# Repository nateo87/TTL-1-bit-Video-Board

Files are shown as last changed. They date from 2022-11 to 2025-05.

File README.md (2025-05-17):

# TTL-1-bit-Video-Board
<s><i><b>UPDATE 2/2/2025:</b></i>

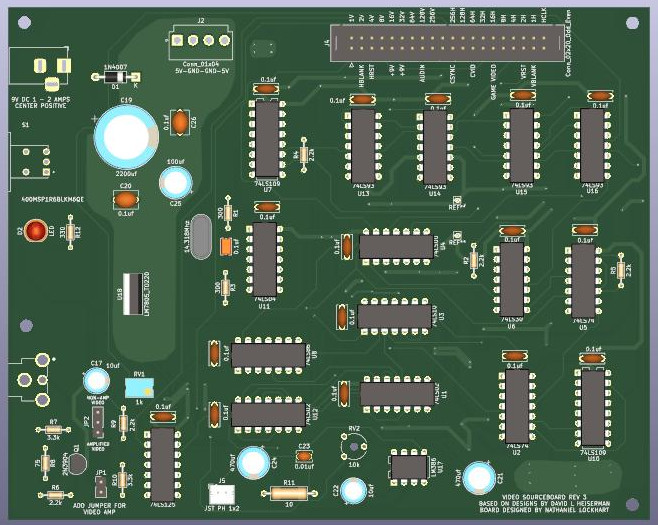
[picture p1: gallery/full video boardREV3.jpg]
new board render from KiCad


Did another revision of the board. The one I had up here previously was one of my first projects in KiCad, moving away from EasyEDA. The main changes with this revision have to do with size: the board is MUCH smaller, and the footprints for a lot of the passive components have been assigned more appropriately sized designs. I also swapped out the no-longer-produced 74LS76 IC with the much easier to source 74LS109. Still functions the exact same, only difference is pinout and 'K' is now active LOW instead of HIGH. ANYWAYS, on to what I wrote previously: </s>

<b>UPDATE: 5/12/2025 </b>
Just built one of the newest revision, and whaddya know, a 74LS109 <i>will not</i> work in place of a 74LS76! I built a board over the weekend, and thought maybe I was dealing with bad PCB design that was creating ringing or cross-talk between signals. But nope - it has to use a <i>negative edge</i> triggered JK flip-flop instead of a positive edge trigger. I bodged in a 74LS112 and all was well. I'm currently working on a revision to use the 74LS112 instead. 

<b>UPDATE: 5/16/2025 </b>
I updated the board to use a (still produced) 74LS112 in place of the non-working 74LS109. Circuit should be fully functional now. Now to design a 3D printed enclosure!

<i>end of update</i>

Here is a TTL-based, 1-bit video board as designed by David L. Heiserman in the book How to Design and Build Your Own Custom TV Games. Corrections have been made from the schematics in the book, mostly just pin number confusions (the later schematics have much more troublesome errors).

The original design has the outputs all going to a card edge connector, but I thought a 40-pin IDC connector would be a little more friendly, and an adapter can easily be purchased so that an IDC cable can plug into a breadboard for experimentation. Another thing that has been changed from the original design is the analog video output. Though it is still B&W composite, the values of the resistors dividing the voltage have changed, in order to massage the signal to be more easily accepted among a wider range of RF modulators and monitors. Some TVs/monitors tend to be a little pickier about the signal being put into them. In my experimentation, most CRT TVs with a direct composite input tend to be more forgiving with the signal. Jumpers can be placed to activate an amplification of the video signal for more selective monitors.

The text of Heiserman's book can easily be found online on [archive.org](https://archive.org/details/howtodesignbuild0000heis_n7e2), and I highly encourage trying some of the builds in the book, if only so that I'm not the only one crazy enough to be working through them! I haven't ordered boards yet from this most recent revision (V3), but once I do, I'll have pics of the assembled product running some experiments. 

Here's a video of an earlier revision of the board running a simple moveable square circuit:
(https://www.youtube.com/watch?v=p2fEVsLSzvE&t=35s)

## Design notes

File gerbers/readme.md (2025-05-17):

Here are the updated gerber files for the smaller video board with the correct, negative-edge JK flip-flop IC used.

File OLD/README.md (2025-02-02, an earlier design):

Here's everything from the earlier revision for posterity. <b>THIS IS NOT CURRENT</b>

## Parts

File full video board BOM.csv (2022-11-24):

Id | Designator | Quantity | Designation
1 | C17, C25 | 2 | 100uf, electrolytic
2 | C19 | 1 | 2200uf, electrolytic
3 | C1,C2,C3,C4,C5,C13,C11,C16,C18,C8,C12,C6,C9,C10,C7,C15,C14,C26,C20 | 19 | 0.1uf
4 | C21,C24 | 2 | 470uf, electrolytic
5 | C22 | 1 | 10uf, electrolytic
6 | C23 | 1 | 0.01uf
7 | D1 | 1 | 1N4007
8 | D2 | 1 | LED
9 | J1 | 1 | RCA Jack
10 | J2 | 1 | 2x20 IDC socket, 2.54mm pitch
11 | J3 | 1 | Barrel_Jack_MountingPin, 5.5x2.1
12 | J4 | 1 | JST VH 1x4
13 | J5 | 1 | JST PH 1x2
14 | JP1 | 1 | 2.54 header pins
15 | JP2 | 1 | 2.54 header pins
16 | Q1 | 1 | 2N3904 or 2N2222
17 | R1,R2 | 2 | 300ohm
18 | R10,R7 | 2 | 3.3k
19 | R11 | 1 | 10ohm
20 | R12 | 1 | 330ohm
21 | R4,R3,R6,R9,R5 | 5 | 2.2k
22 | R8 | 1 | 75ohm
23 | RV1 | 1 | 10k pot
24 | RV2 | 1 | Bourns trim pot, 1k
25 | S1 | 1 | 300SP1J1BLKM6QE, switch
26 | U1 | 1 | 74LS04
27 | U10,U2 | 2 | 74LS76
28 | U12,U3,U11,U4 | 4 | 74LS93
29 | U13,U15 | 2 | 74LS02
30 | U14 | 1 | 74LS86
31 | U16 | 1 | 74LS125
32 | U18 | 1 | LM386
33 | U19 | 1 | LM78S05
34 | U6 | 1 | 74LS00
35 | U7 | 1 | 74LS30
36 | U8 | 1 | 74LS10
37 | U9,U5 | 2 | 74LS74
38 | Y1 | 1 | 14.318Mhz

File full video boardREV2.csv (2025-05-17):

Source: | C:\Users\nateo\OneDrive\Documents\power supply\full video board\full video boardREV2.kicad_sch
Date: | 5/16/2025 11:02:02 PM
Tool: | Eeschema (6.0.5)
Generator: | C:\Program Files\KiCad\6.0\bin\scripting\plugins/bom_csv_grouped_by_value_with_fp.py
Component Count: | 70
Ref | Qnty | Value | Cmp name | Footprint | Description | Vendor
C1, C2, C3, C4, C5, C6, C7, C8, C9, C10, C11, C12, C14, C15, C16, C18, | 16 | 0.1uf | C | Capacitor_THT:C_Disc_D6.0mm_W2.5mm_P5.00mm | Unpolarized capacitor
C13, | 1 | 0.1uf | C | Capacitor_THT:C_Rect_L4.0mm_W2.5mm_P2.50mm | Unpolarized capacitor
C17, C22, | 2 | 10uf | C_Polarized | Capacitor_THT:CP_Radial_D6.3mm_P2.50mm | Polarized capacitor
C19, | 1 | 2200uf | C_Polarized | Capacitor_THT:CP_Radial_D16.0mm_P7.50mm | Polarized capacitor
C20, C26, | 2 | 0.1uf | C | Capacitor_THT:C_Disc_D6.0mm_W4.4mm_P5.00mm | Unpolarized capacitor
C21, C24, | 2 | 470uf | C_Polarized | Capacitor_THT:CP_Radial_D8.0mm_P3.80mm | Polarized capacitor
C23, | 1 | 0.01uf | C | Capacitor_THT:C_Disc_D3.8mm_W2.6mm_P2.50mm | Unpolarized capacitor
C25, | 1 | 100uf | C_Polarized | Capacitor_THT:CP_Radial_D8.0mm_P3.50mm | Polarized capacitor
D1, | 1 | 1N4007 | 1N4007 | Diode_THT:D_DO-41_SOD81_P10.16mm_Horizontal | 1000V 1A General Purpose Rectifier Diode, DO-41
D2, | 1 | LED | LED | LED_THT:LED_D5.0mm | Light emitting diode
J1, | 1 | RCJ-014 | RCJ-014 | footprints:CUI_RCJ-014
J2, | 1 | Conn_01x04 | Conn_01x04 | Connector_JST:JST_VH_B4P-VH-B_1x04_P3.96mm_Vertical | Generic connector, single row, 01x04, script generated (kicad-library-utils/schlib/autogen/connector/)
J3, | 1 | Barrel_Jack_MountingPin | Barrel_Jack | Connector_BarrelJack:BarrelJack_Horizontal | DC Barrel Jack
J4, | 1 | Conn_02x20_Odd_Even | Conn_02x20_Odd_Even | Connector_IDC:IDC-Header_2x20_P2.54mm_Vertical | Generic connector, double row, 02x20, odd/even pin numbering scheme (row 1 odd numbers, row 2 even numbers), script generated (kicad-library-utils/schlib/autogen/connector/)
J5, | 1 | JST PH 1x2 | Conn_01x02 | Connector_JST:JST_PH_B2B-PH-K_1x02_P2.00mm_Vertical | Generic connector, single row, 01x02, script generated (kicad-library-utils/schlib/autogen/connector/)
JP1, | 1 | Jumper_2_Open | Jumper_2_Open | Connector_PinHeader_2.54mm:PinHeader_1x02_P2.54mm_Vertical | Jumper, 2-pole, open
JP2, | 1 | Jumper_3_Open | Jumper_3_Open | Connector_PinHeader_2.54mm:PinHeader_1x03_P2.54mm_Vertical | Jumper, 3-pole, both open
Q1, | 1 | 2N3904 | 2N3904 | Package_TO_SOT_THT:TO-92_Inline | 0.2A Ic, 40V Vce, Small Signal NPN Transistor, TO-92
R1, R3, | 2 | 300 | R | Resistor_THT:R_Axial_DIN0204_L3.6mm_D1.6mm_P7.62mm_Horizontal | Resistor
R2, R4, R5, R6, R9, | 5 | 2.2k | R | Resistor_THT:R_Axial_DIN0204_L3.6mm_D1.6mm_P7.62mm_Horizontal | Resistor
R7, R10, | 2 | 3.3k | R | Resistor_THT:R_Axial_DIN0204_L3.6mm_D1.6mm_P7.62mm_Horizontal | Resistor
R8, | 1 | 75 | R | Resistor_THT:R_Axial_DIN0204_L3.6mm_D1.6mm_P7.62mm_Horizontal | Resistor
R11, | 1 | 10 | R | Resistor_THT:R_Axial_DIN0309_L9.0mm_D3.2mm_P12.70mm_Horizontal | Resistor
R12, | 1 | 330 | R | Resistor_THT:R_Axial_DIN0204_L3.6mm_D1.6mm_P7.62mm_Horizontal | Resistor
RV1, | 1 | 1k | R_Potentiometer | Potentiometer_THT:Potentiometer_Bourns_3266Y_Vertical | Potentiometer
RV2, | 1 | 10k | R_Potentiometer_US | Potentiometer_THT:Potentiometer_Piher_PT-6-V_Vertical_Hole | Potentiometer, US symbol
S1, | 1 | 400MSP1R6BLKM6QE | 300SP1J1BLKM6QE | 300SP1J1BLKM6QE:SW_400MSP1R6BLKM6QE
U1, U12, | 2 | 74LS02 | 74LS02 | Package_DIP:DIP-14_W7.62mm | quad 2-input NOR gate
U2, U5, | 2 | 74LS74 | 74LS74 | Package_DIP:DIP-14_W7.62mm | Dual D Flip-flop, Set & Reset
U3, | 1 | 74LS10 | 74LS10 | Package_DIP:DIP-14_W7.62mm | Triple 3-input NAND
U4, | 1 | 74LS00 | 74LS00 | Package_DIP:DIP-14_W7.62mm | quad 2-input NAND gate
U6, | 1 | 74LS30 | 74LS30 | Package_DIP:DIP-14_W7.62mm | 8-input NAND
U7, U10, | 2 | 74LS112 | 74LS112 | Package_DIP:DIP-16_W7.62mm | dual JK Flip-Flop, Set & Reset
U8, | 1 | 74LS86 | 74LS86 | Package_DIP:DIP-14_W7.62mm | Quad 2-input XOR
U9, | 1 | 74LS125 | 74LS125 | Package_DIP:DIP-14_W7.62mm | Quad buffer 3-State outputs
U11, | 1 | 74LS04 | 74LS04 | Package_DIP:DIP-14_W7.62mm | Hex Inverter
U13, U14, U15, U16, | 4 | 74LS93 | 74LS93 | Package_DIP:DIP-14_W7.62mm | Divide by 2 & 8 counter
U17, | 1 | LM386 | LM386 | Package_DIP:DIP-8_W7.62mm | Low Voltage Audio Power Amplifier, DIP-8/SOIC-8/SSOP-8
U18, | 1 | LM7805_TO220 | LM7805_TO220 | Package_TO_SOT_THT:TO-220-3_Vertical | Positive 1A 35V Linear Regulator, Fixed Output 5V, TO-220
Y1, | 1 | 14.318Mhz | Crystal | Crystal:Crystal_HC18-U_Vertical | Two pin crystal

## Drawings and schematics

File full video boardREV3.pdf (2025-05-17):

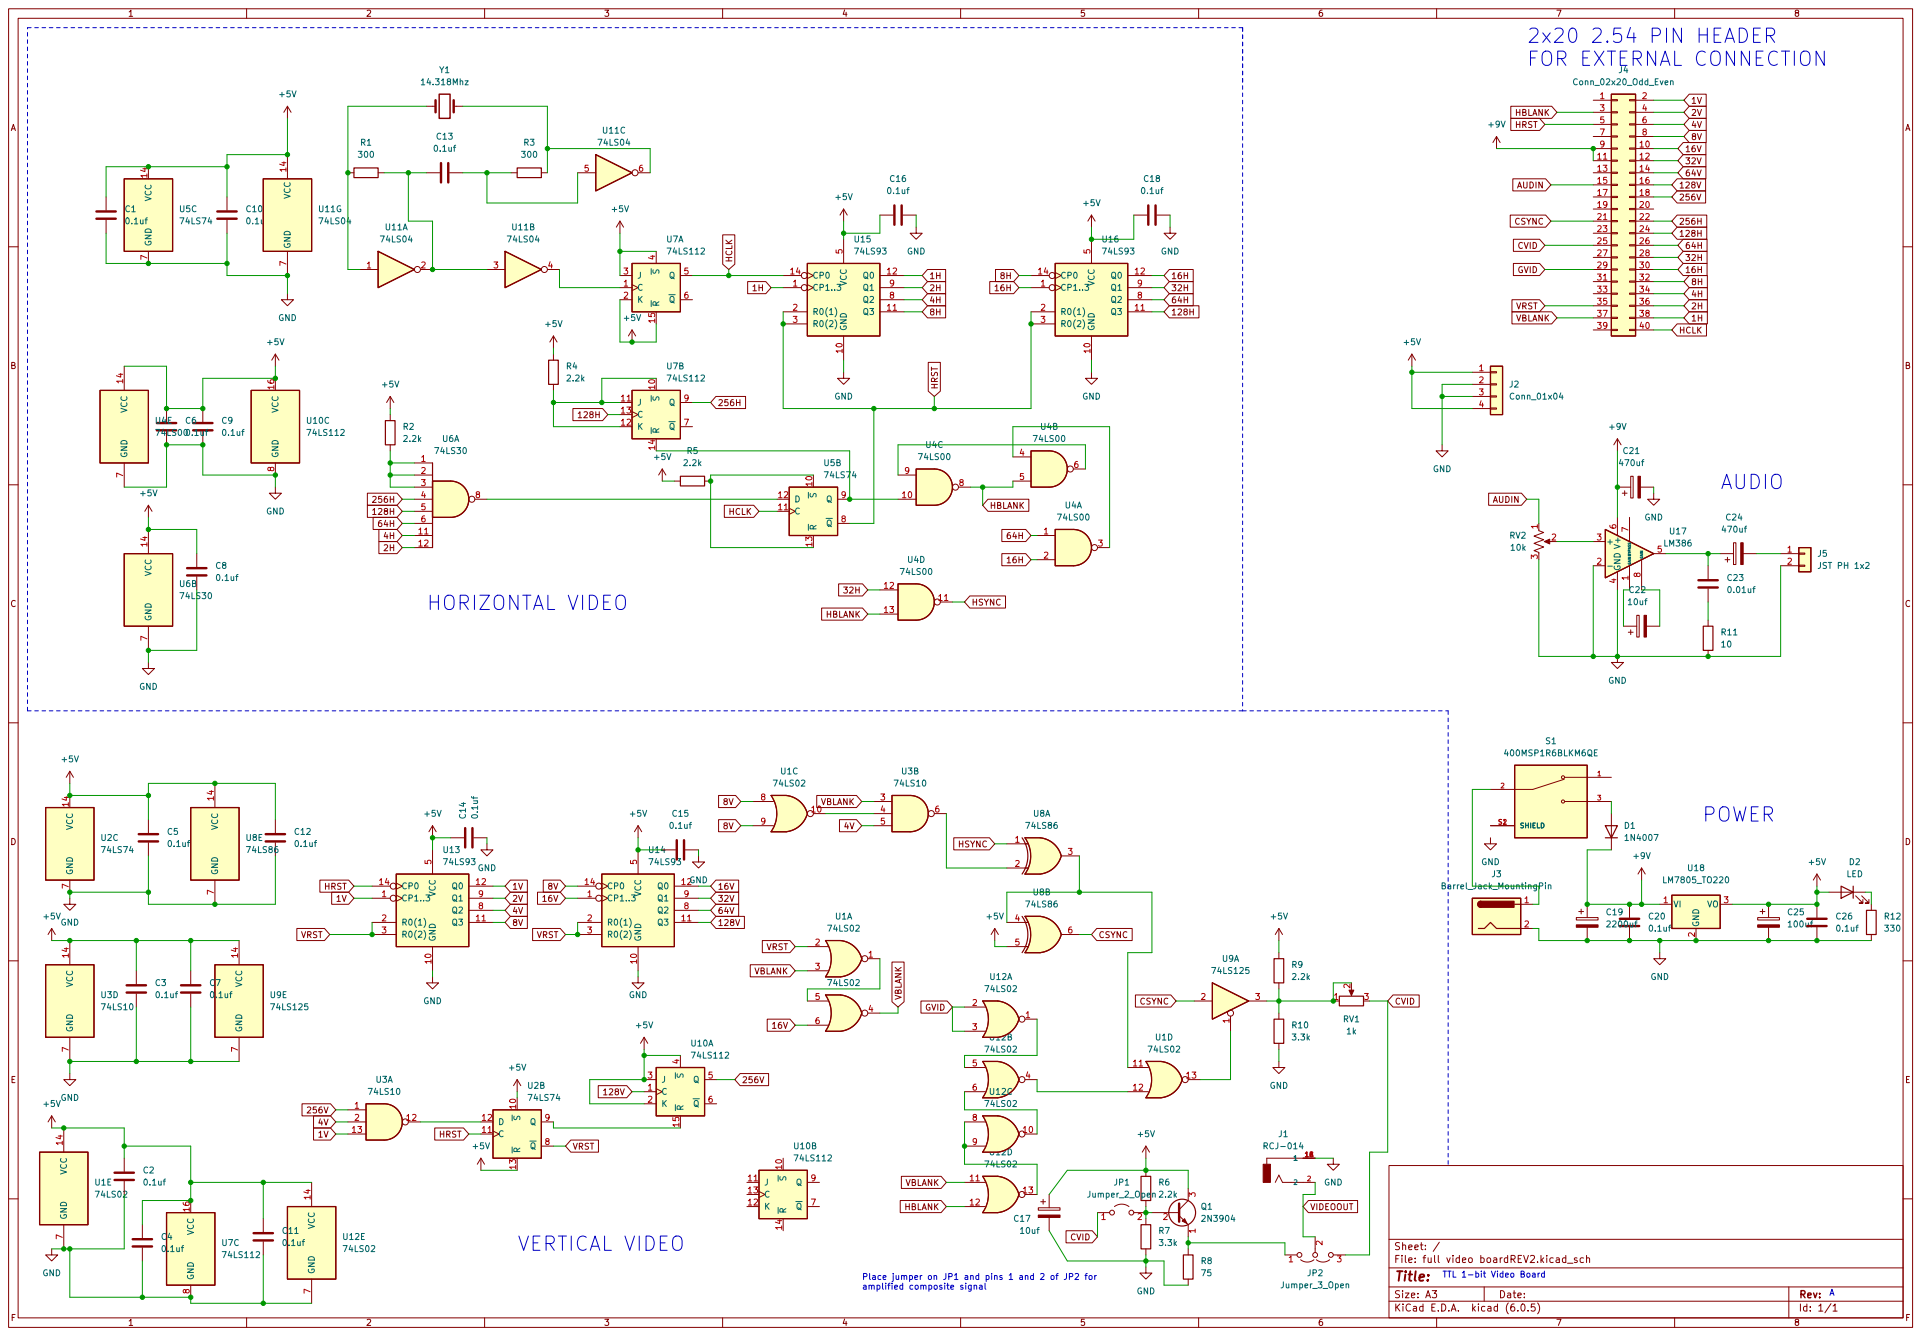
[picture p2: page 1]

File: full video boardREV2.kicad_sch Sheet: /

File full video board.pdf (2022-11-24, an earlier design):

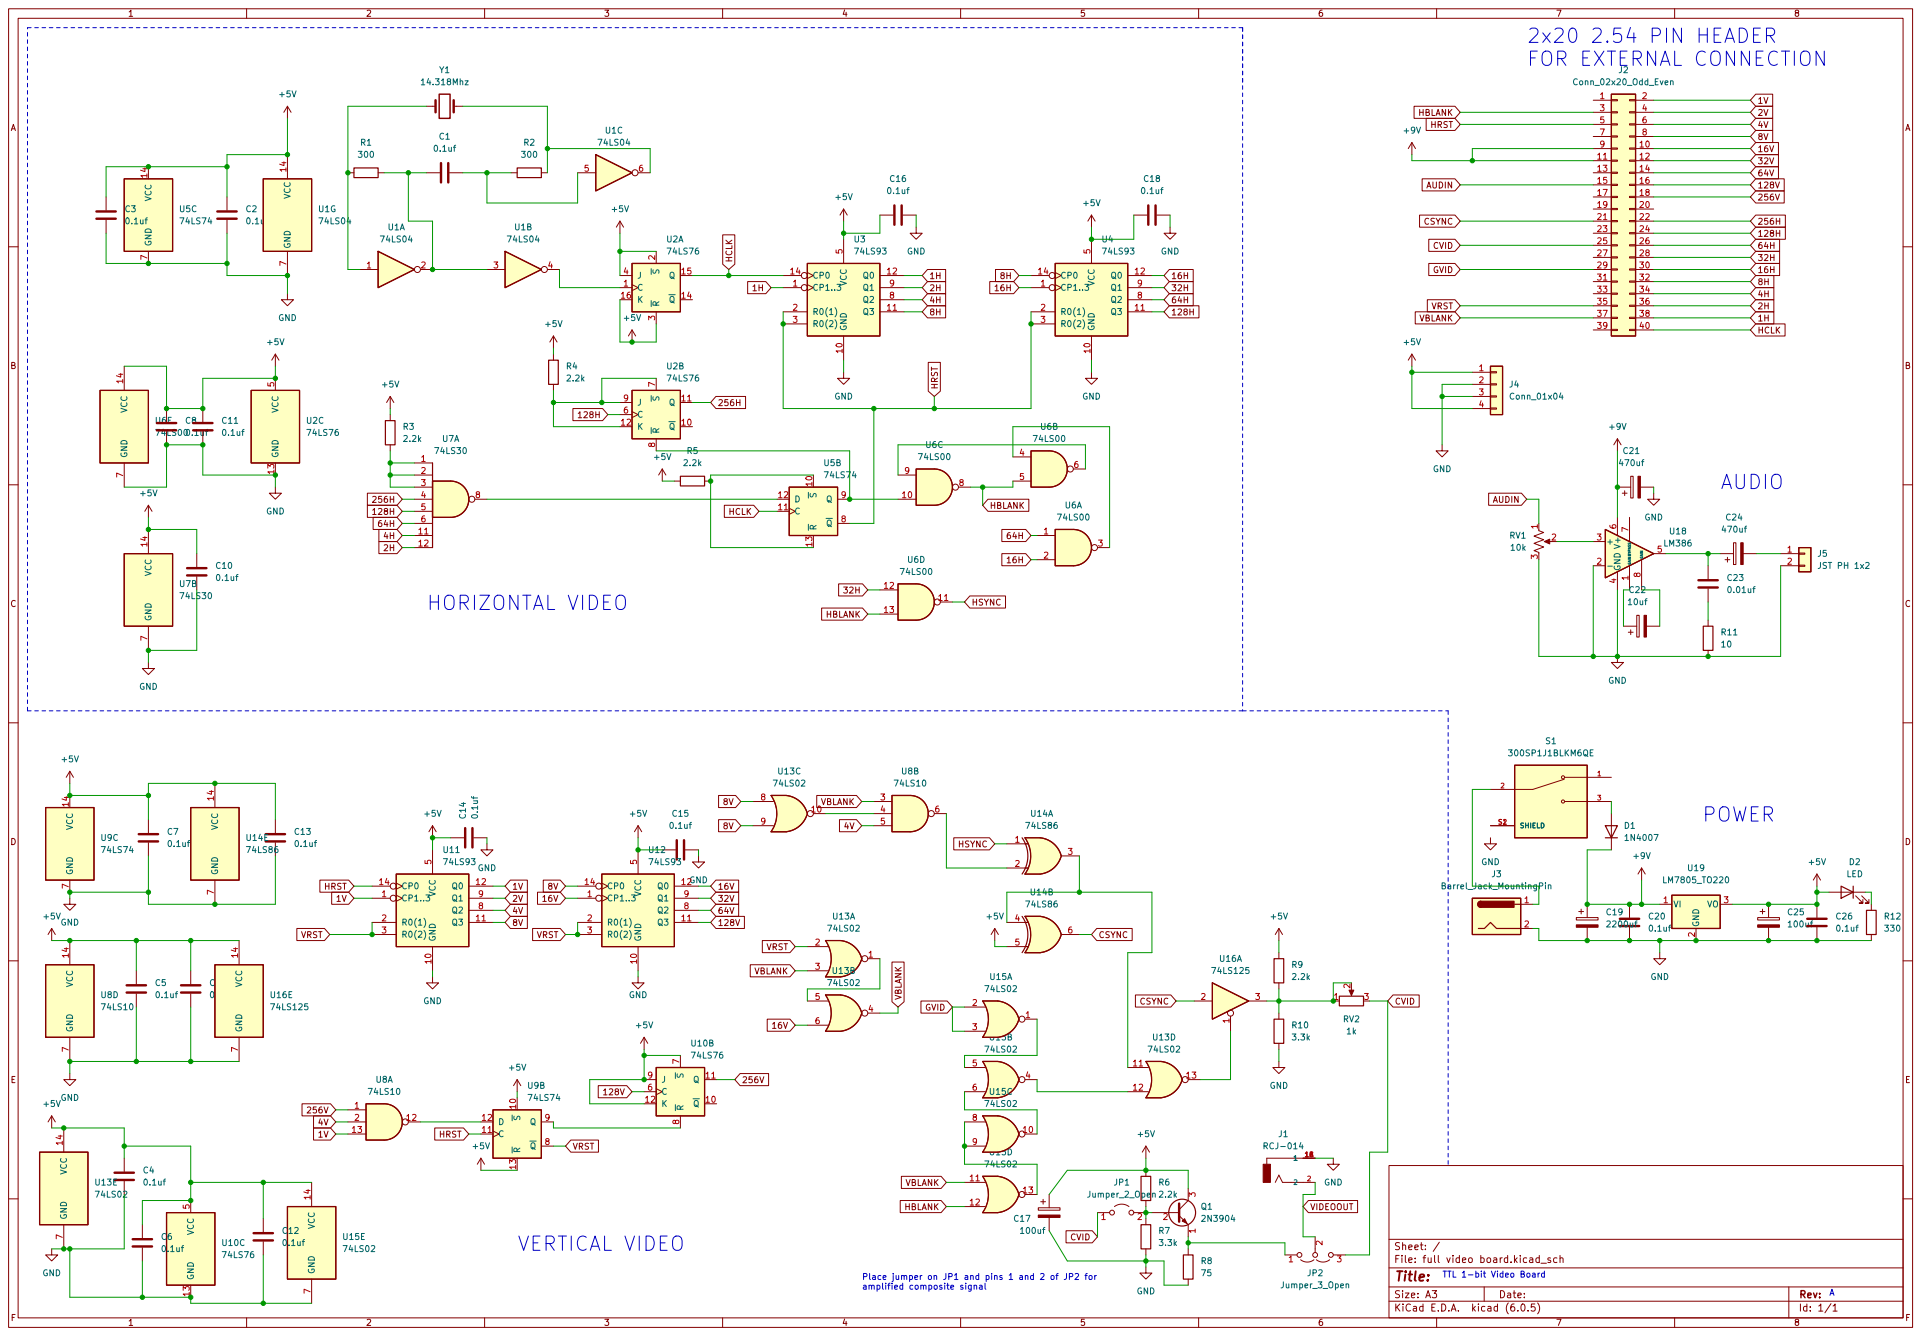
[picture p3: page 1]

File: full video board.kicad_sch Sheet: /

Place jumper on JP1 and pins 1 and 2 of JP2 for
amplified composite signal

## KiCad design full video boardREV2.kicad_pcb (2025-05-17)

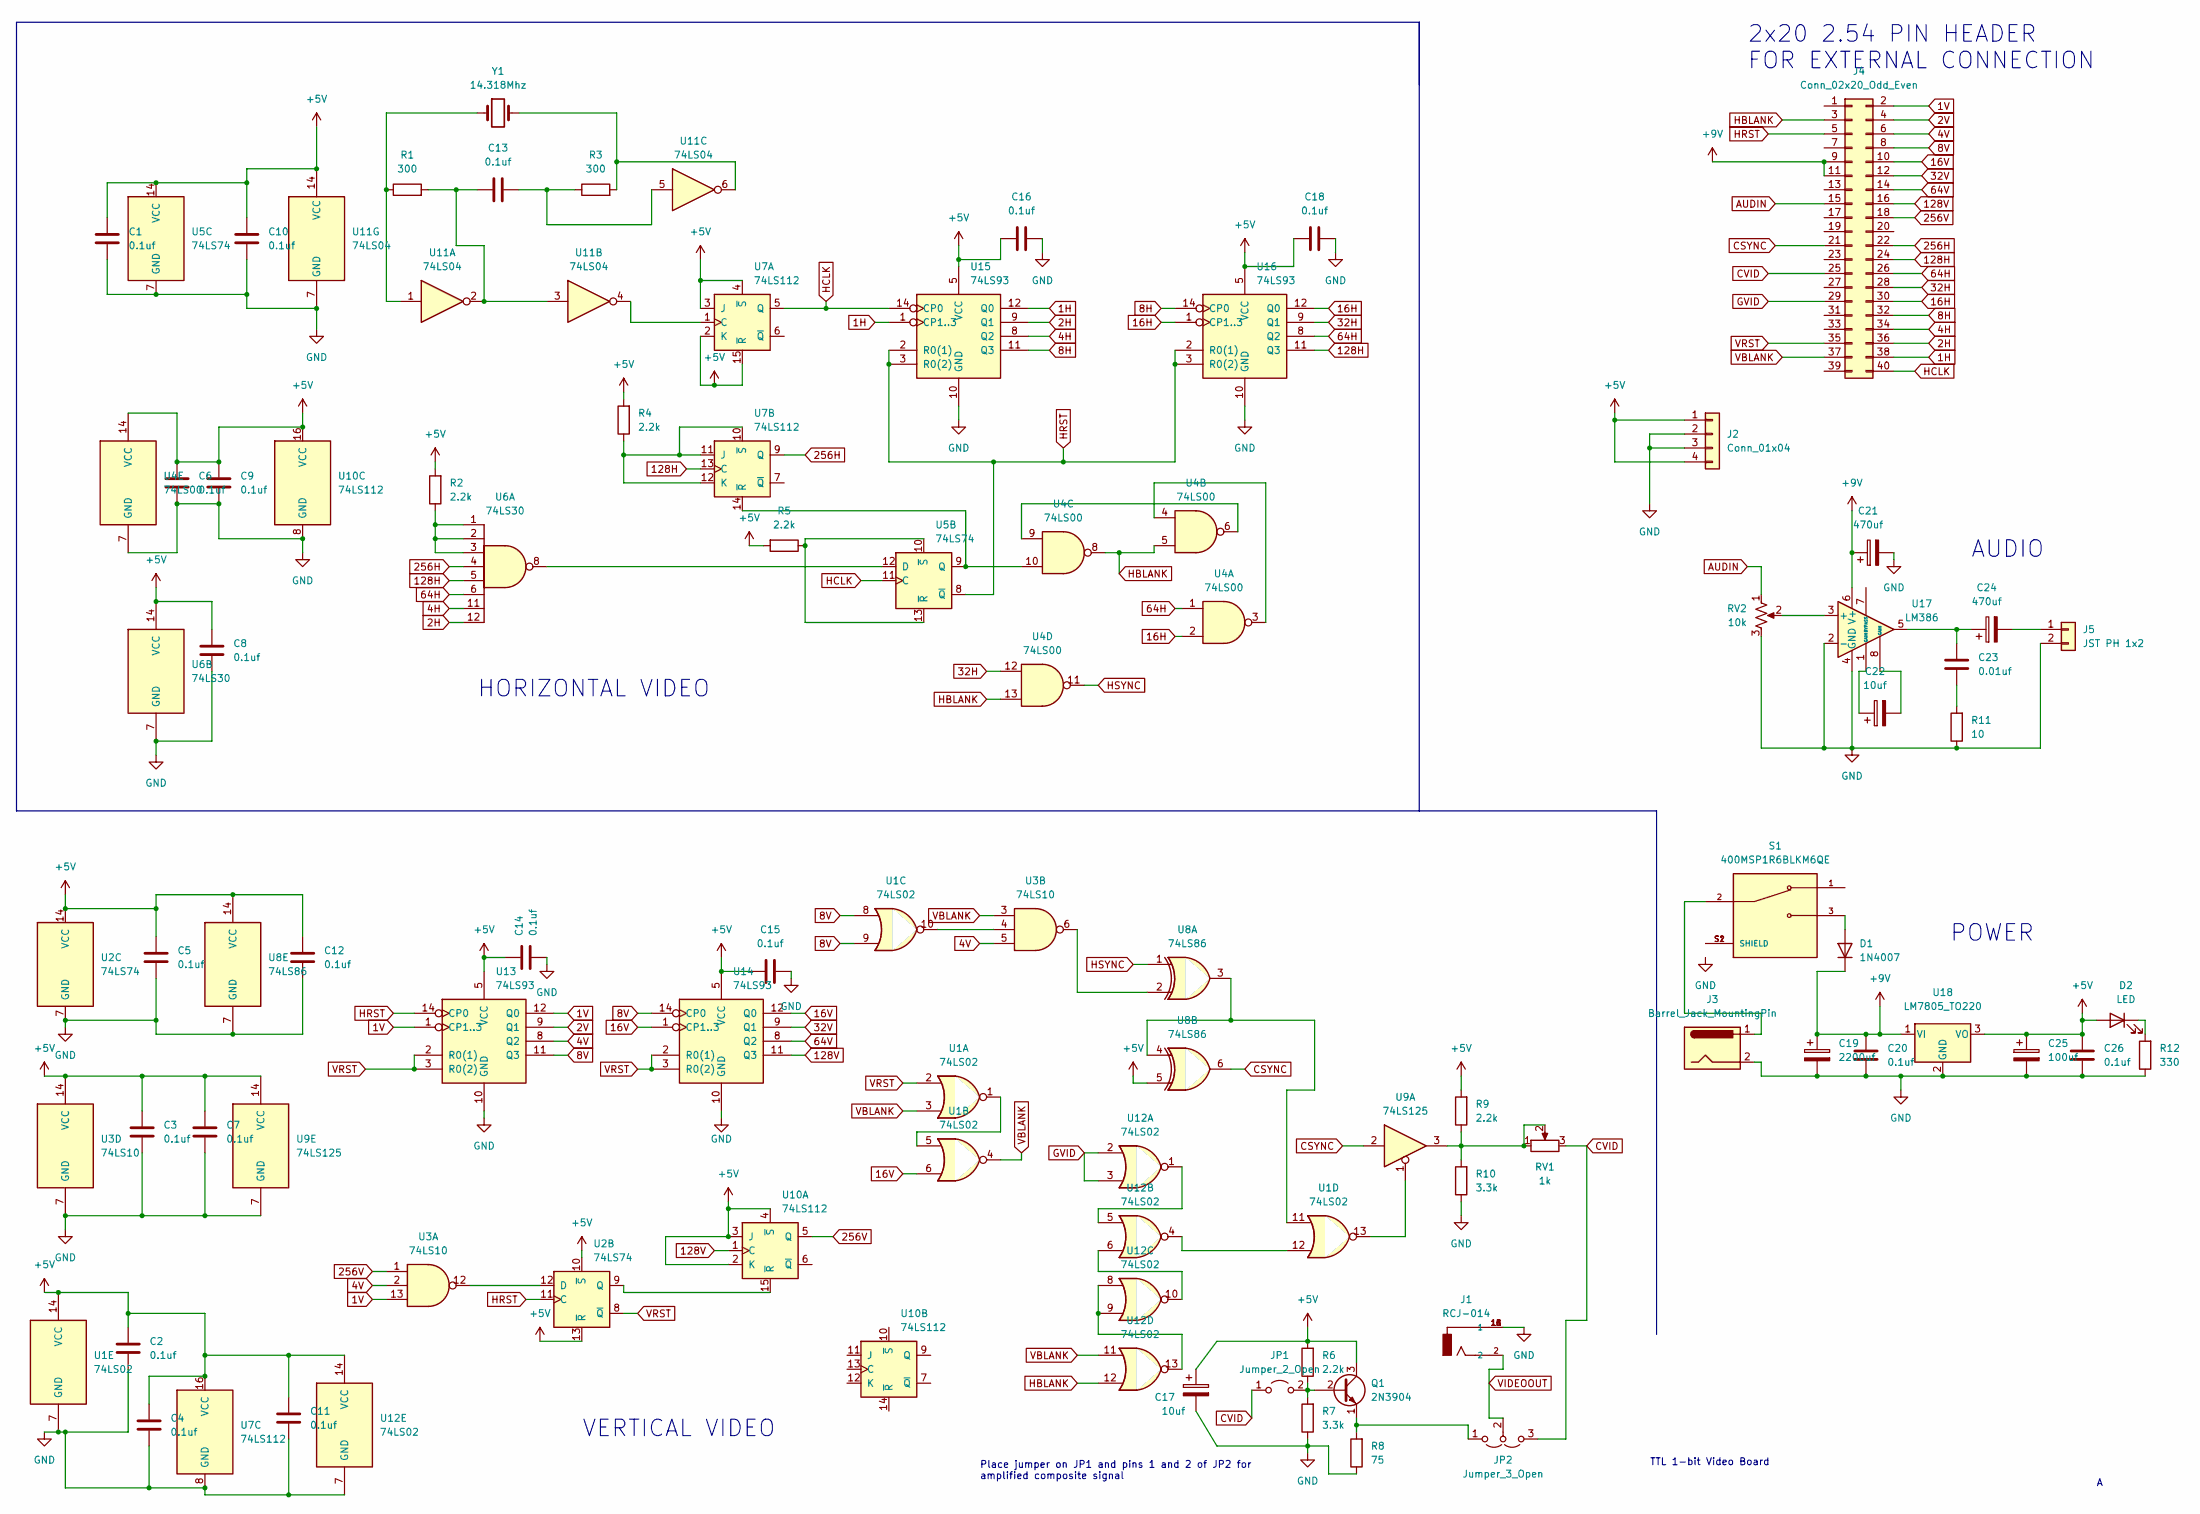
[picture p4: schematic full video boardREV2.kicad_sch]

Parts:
C1, C2, C3, C4, C5, C6, C7, C8, C9, C10, C11, C12, C14, C15, C16, C18: 0.1uf; C_Disc_D6.0mm_W2.5mm_P5.00mm
C13: 0.1uf; C_Rect_L4.0mm_W2.5mm_P2.50mm
C17, C22: 10uf; CP_Radial_D6.3mm_P2.50mm
C19: 2200uf; CP_Radial_D16.0mm_P7.50mm
C20, C26: 0.1uf; C_Disc_D6.0mm_W4.4mm_P5.00mm
C21, C24: 470uf; CP_Radial_D8.0mm_P3.80mm
C23: 0.01uf; C_Disc_D3.8mm_W2.6mm_P2.50mm
C25: 100uf; CP_Radial_D8.0mm_P3.50mm
D1: 1N4007; D_DO-41_SOD81_P10.16mm_Horizontal
D2: LED; LED_D5.0mm
J1: RCJ-014; CUI_RCJ-014; PART_REV B
J2: Conn_01x04; JST_VH_B4P-VH-B_1x04_P3.96mm_Vertical
J3: Barrel_Jack_MountingPin; BarrelJack_Horizontal
J4: Conn_02x20_Odd_Even; IDC-Header_2x20_P2.54mm_Vertical
J5: JST PH 1x2; JST_PH_B2B-PH-K_1x02_P2.00mm_Vertical
JP1: Jumper_2_Open; PinHeader_1x02_P2.54mm_Vertical
JP2: Jumper_3_Open; PinHeader_1x03_P2.54mm_Vertical
Q1: 2N3904; TO-92_Inline
R1, R3: 300; R_Axial_DIN0204_L3.6mm_D1.6mm_P7.62mm_Horizontal
R2, R4, R5, R6, R9: 2.2k; R_Axial_DIN0204_L3.6mm_D1.6mm_P7.62mm_Horizontal
R7, R10: 3.3k; R_Axial_DIN0204_L3.6mm_D1.6mm_P7.62mm_Horizontal
R8: 75; R_Axial_DIN0204_L3.6mm_D1.6mm_P7.62mm_Horizontal
R11: 10; R_Axial_DIN0309_L9.0mm_D3.2mm_P12.70mm_Horizontal
R12: 330; R_Axial_DIN0204_L3.6mm_D1.6mm_P7.62mm_Horizontal
RV1: 1k; Potentiometer_Bourns_3266Y_Vertical
RV2: 10k; Potentiometer_Piher_PT-6-V_Vertical_Hole
S1: 400MSP1R6BLKM6QE; SW_400MSP1R6BLKM6QE; PARTREV F
U1, U12: 74LS02; DIP-14_W7.62mm
U2, U5: 74LS74; DIP-14_W7.62mm
U3: 74LS10; DIP-14_W7.62mm
U4: 74LS00; DIP-14_W7.62mm
U6: 74LS30; DIP-14_W7.62mm
U7, U10: 74LS112
U8: 74LS86; DIP-14_W7.62mm
U9: 74LS125; DIP-14_W7.62mm
U11: 74LS04; DIP-14_W7.62mm
U13, U14, U15, U16: 74LS93; DIP-14_W7.62mm
U17: LM386; DIP-8_W7.62mm
U18: LM7805_TO220; TO-220-3_Vertical
Y1: 14.318Mhz; Crystal_HC18-U_Vertical

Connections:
1H: J4.38, U15.1 (CP1..3), U15.12 (Q0)
1V: J4.2, U3.13, U13.1 (CP1..3), U13.12 (Q0)
2H: J4.36, U6.12, U15.9 (Q1)
2V: J4.4, U13.9 (Q1)
4H: J4.34, U6.11, U15.8 (Q2)
4V: J4.6, U3.2, U3.5, U13.8 (Q2)
8H: J4.32, U15.11 (Q3), U16.14 (CP0)
8V: J4.8, U1.8, U1.9, U13.11 (Q3), U14.14 (CP0)
16H: J4.30, U4.2, U16.1 (CP1..3), U16.12 (Q0)
16V: J4.10, U1.6, U14.1 (CP1..3), U14.12 (Q0)
32H: J4.28, U4.12, U16.9 (Q1)
32V: J4.12, U14.9 (Q1)
64H: J4.26, U4.1, U6.6, U16.8 (Q2)
64V: J4.14, U14.8 (Q2)
128H: J4.24, U6.5, U7.13 (C), U16.11 (Q3)
128V: J4.16, U10.1 (C), U14.11 (Q3)
256H: J4.22, U6.4, U7.9 (Q)
256V: J4.18, U3.1, U10.5 (Q)
+5V: C1.1, C2.1, C3.1, C4.1, C5.1, C6.1, C7.1, C8.1, C9.1, C10.1, C11.1, C12.1, C14.1, C15.1, C16.1, C17.1, C18.1, C25.1, C26.1, D2.2 (A), J2.1, J2.4, Q1.3 (C), R2.2, R4.2, R5.2, R6.2, R9.2, U1.14 (VCC), U2.10 (~S), U2.13 (~R), U2.14 (VCC), U3.14 (VCC), U4.14 (VCC), U5.14 (VCC), U6.14 (VCC), U7.2 (K), U7.3 (J), U7.4 (~S), U7.15 (~R), U7.16 (VCC), U8.5, U8.14 (VCC), U9.14 (VCC), U10.2 (K), U10.3 (J), U10.4 (~S), U10.16 (VCC), U11.14 (VCC), U12.14 (VCC), U13.5 (VCC), U14.5 (VCC), U15.5 (VCC), U16.5 (VCC), U18.3 (VO)
+9V: C19.1, C20.1, C21.1, D1.1 (K), J4.9, J4.11, U17.6 (V+), U18.1 (VI)
AUDIN: J4.15, RV2.1
CSYNC: J4.21, U8.6, U9.2
CVID: J4.25, JP1.1 (A), JP2.3 (B), RV1.3
GVID: J4.29, U12.2, U12.3
HBLANK: J4.3, U4.5, U4.8, U4.13, U12.12
HCLK: J4.40, U5.11 (C), U7.5 (Q), U15.14 (CP0)
HRST: J4.5, U2.11 (C), U5.8 (~Q), U13.14 (CP0), U15.2 (R0(1)), U15.3 (R0(2)), U16.2 (R0(1)), U16.3 (R0(2))
HSYNC: U4.11, U8.1
unnamed: C13.1, R3.1, U11.5
unnamed: C13.2, R1.2, U11.2, U11.3
unnamed: C22.1, U17.1 (GAIN)
unnamed: C22.2, U17.8 (GAIN)
unnamed: C23.1, C24.1, U17.5
unnamed: C23.2, R11.2
unnamed: C24.2, J5.1
unnamed: D1.2 (A), S1.3
unnamed: D2.1 (K), R12.2
unnamed: J3.1, S1.2
unnamed: JP1.2 (B), Q1.2 (B), R6.1, R7.2
unnamed: JP2.1 (A), Q1.1 (E), R8.2
unnamed: R1.1, U11.1, Y1.1
unnamed: R2.1, U6.1, U6.2, U6.3
unnamed: R3.2, U11.6, Y1.2
unnamed: R4.1, U7.10 (~S), U7.11 (J), U7.12 (K)
unnamed: R5.1, U5.10 (~S), U5.13 (~R)
unnamed: R9.1, R10.2, RV1.1, RV1.2, U9.3
unnamed: RV2.2, U17.3 (+)
unnamed: U1.1, U1.5
unnamed: U1.10, U3.4
unnamed: U1.11, U8.3, U8.4
unnamed: U1.12, U12.4
unnamed: U1.13, U9.1
unnamed: U2.12 (D), U3.12
unnamed: U3.6, U8.2
unnamed: U4.3, U4.4
unnamed: U4.6, U4.9
unnamed: U4.10, U5.9 (Q), U7.14 (~R)
unnamed: U5.12 (D), U6.8
unnamed: U2.9 (Q), U10.15 (~R)
unnamed: U7.1 (C), U11.4
unnamed: U12.1, U12.5
unnamed: U12.6, U12.10
unnamed: U12.8, U12.9, U12.13
VBLANK: J4.37, U1.3, U1.4, U3.3, U12.11
VIDEOOUT: J1.2, JP2.2 (C)
VRST: J4.35, U1.2, U2.8 (~Q), U13.2 (R0(1)), U13.3 (R0(2)), U14.2 (R0(1)), U14.3 (R0(2))

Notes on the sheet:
Place jumper on JP1 and pins 1 and 2 of JP2 for amplified composite signal
TTL 1-bit Video Board
POWER
HORIZONTAL VIDEO
2x20 2.54 PIN HEADER FOR EXTERNAL CONNECTION
AUDIO
VERTICAL VIDEO

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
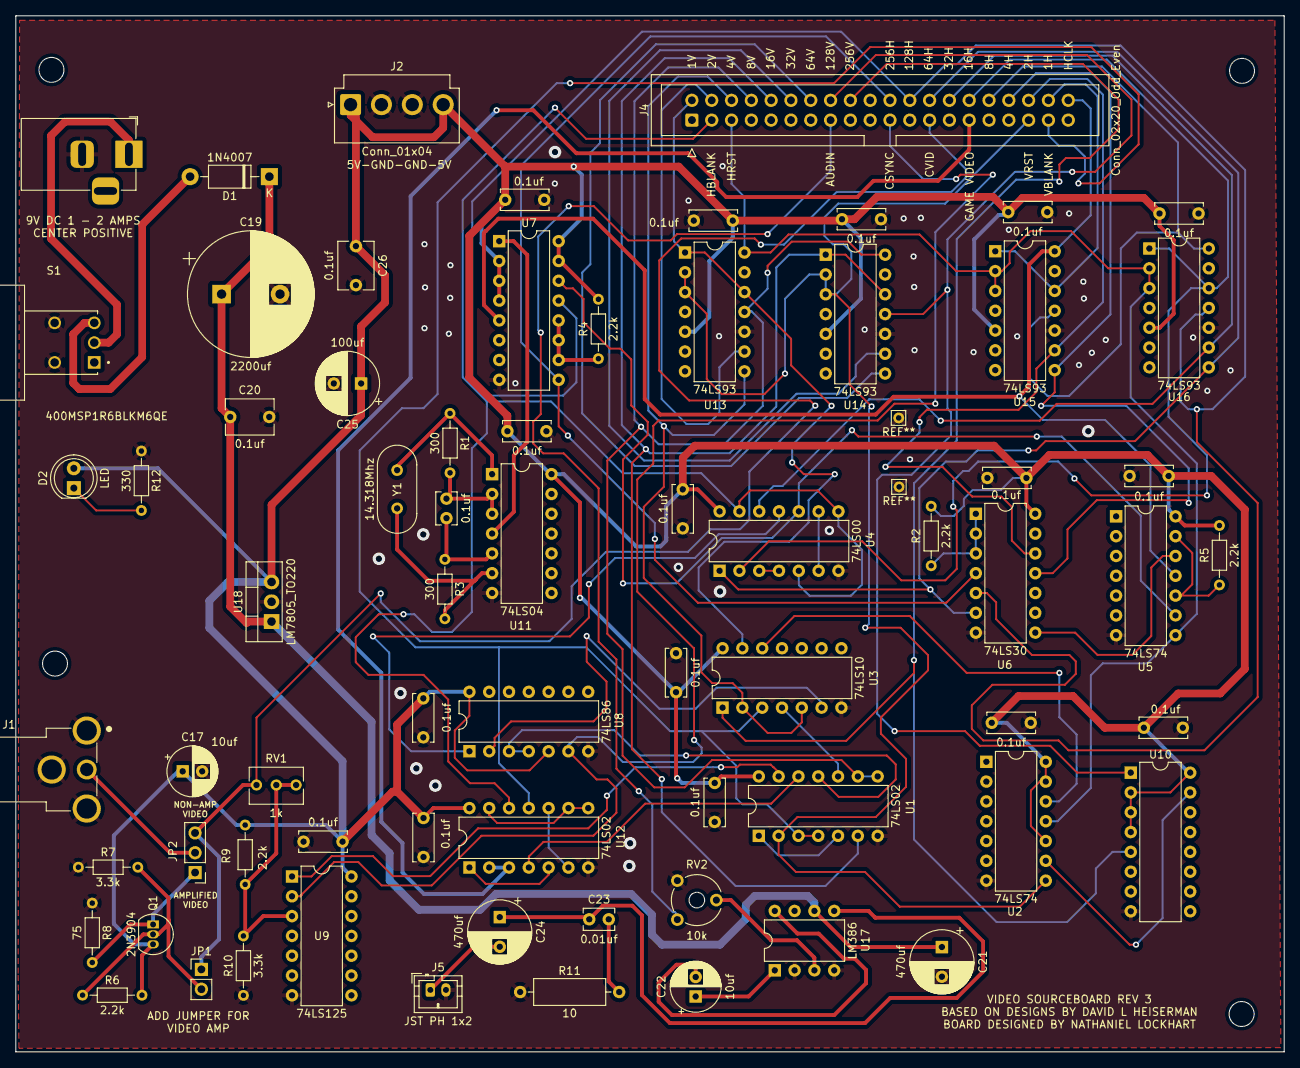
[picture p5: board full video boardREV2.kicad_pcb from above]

Board: 2 copper layers, 162.6 x 132.8 mm, 70 parts (0 on the bottom side), 67 nets.

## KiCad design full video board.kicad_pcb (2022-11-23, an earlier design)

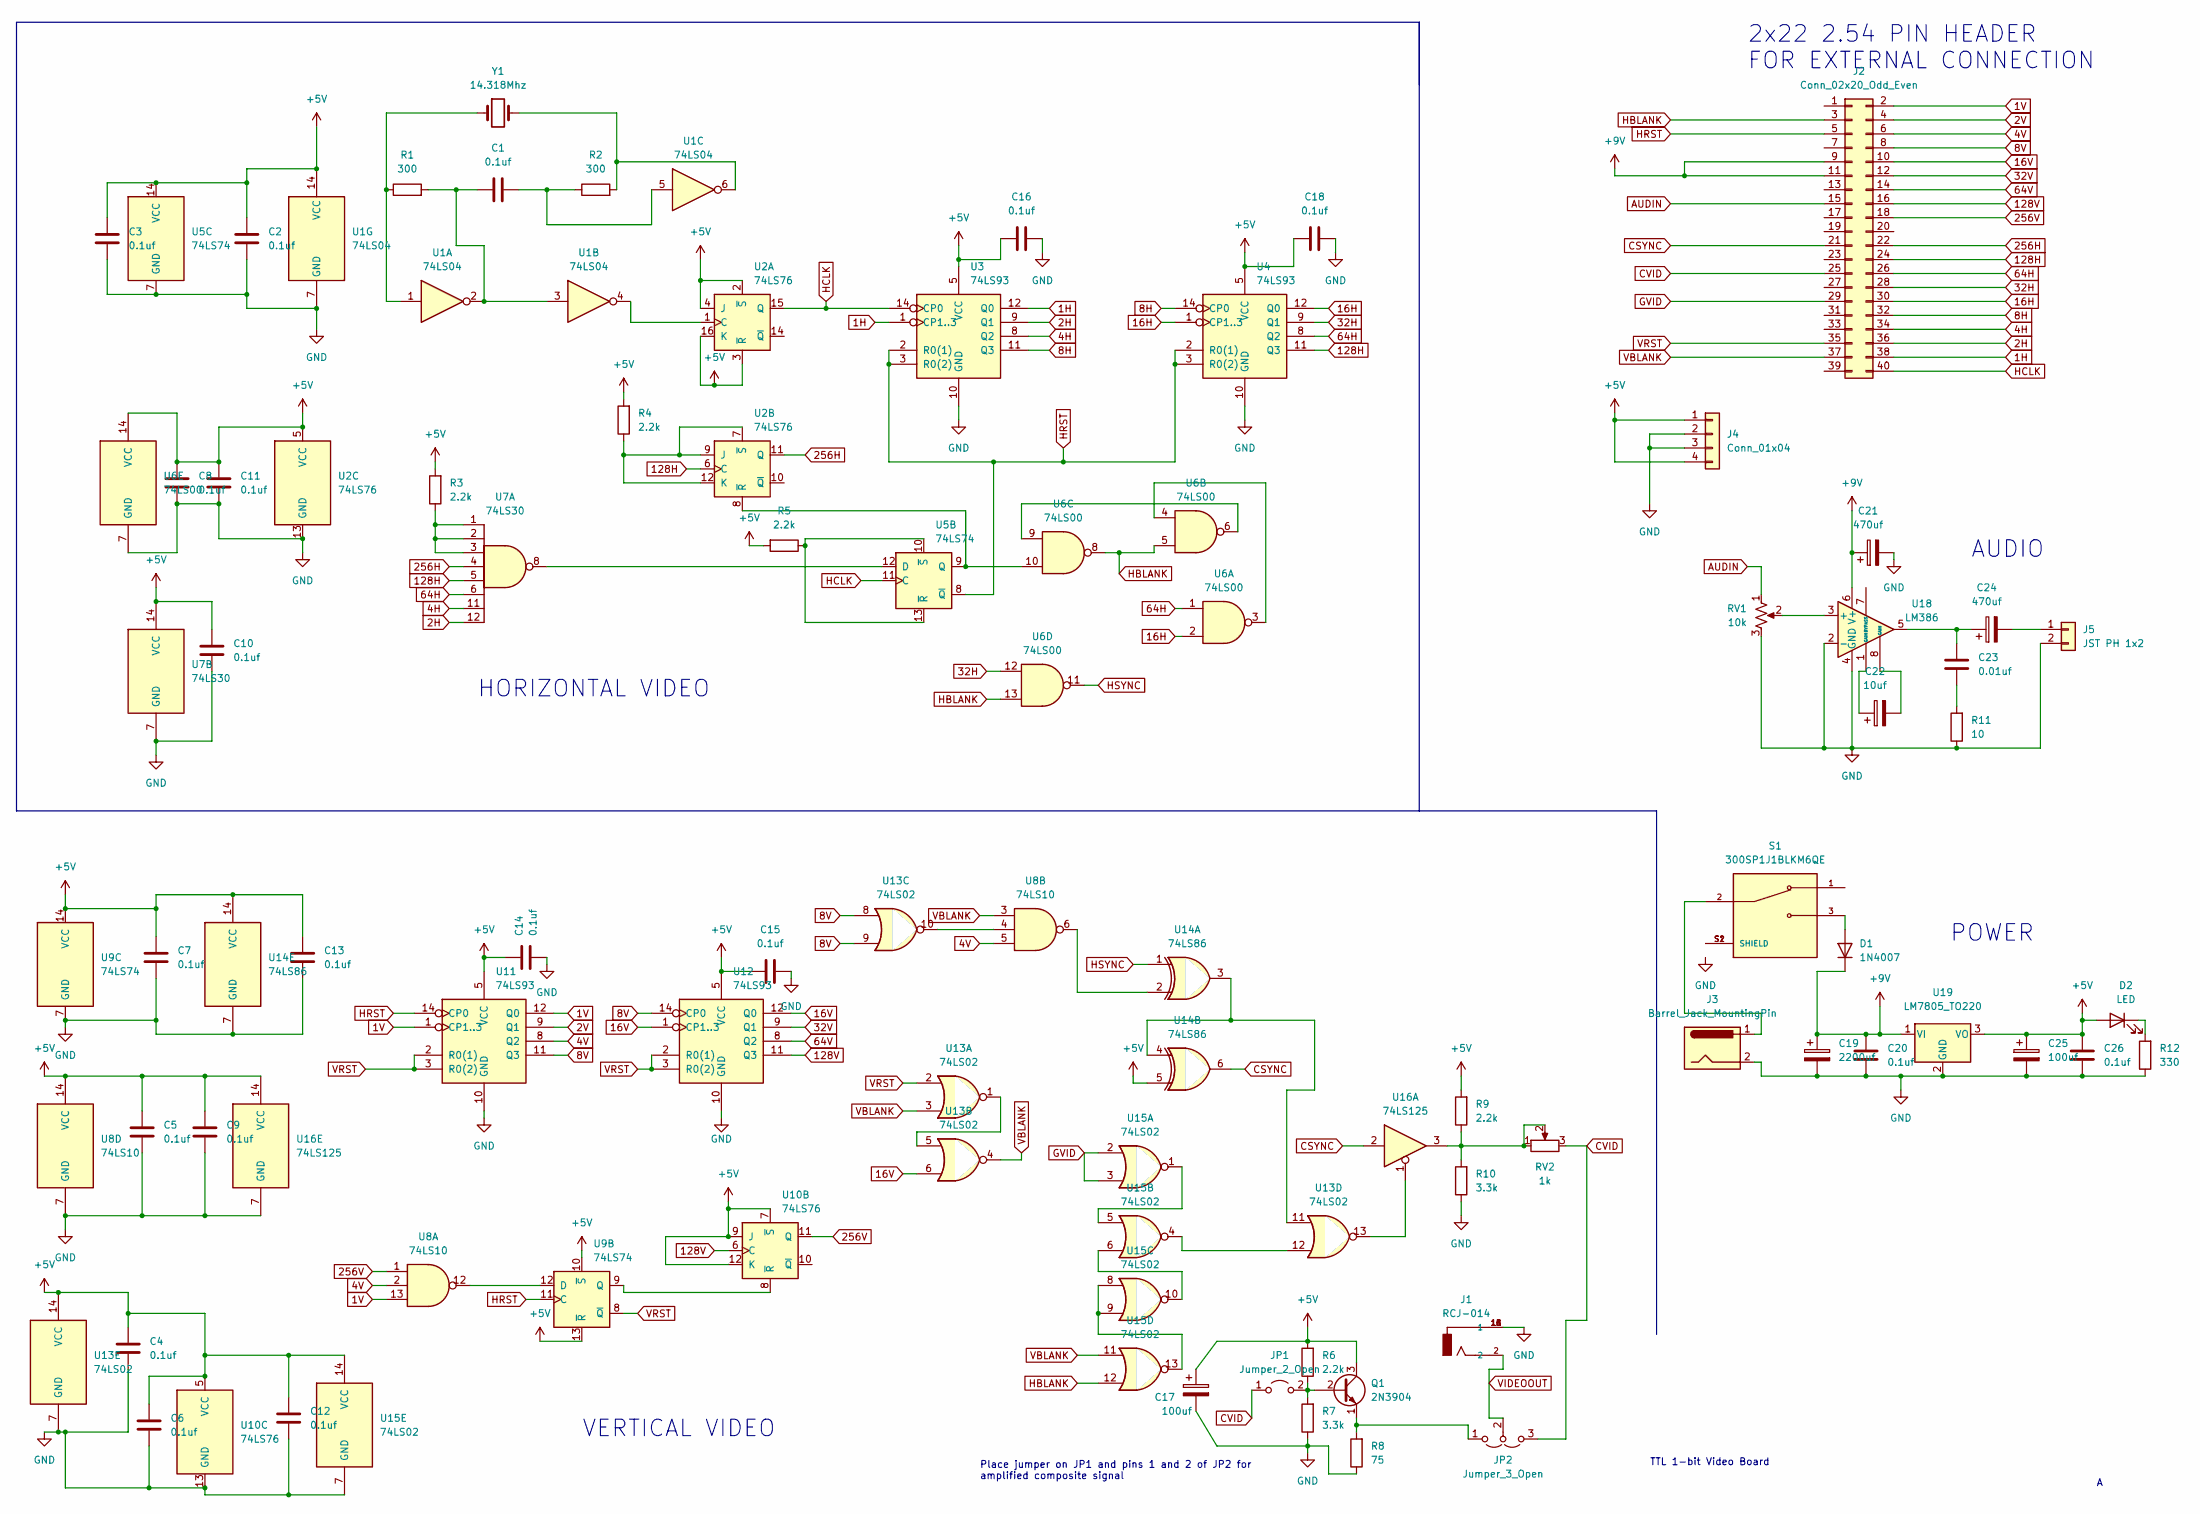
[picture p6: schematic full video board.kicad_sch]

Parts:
C1: 0.1uf; C_Rect_L4.0mm_W2.5mm_P2.50mm
C2, C3, C4, C5, C6, C7, C8, C9, C10, C11, C12, C13, C14, C15, C16, C18: 0.1uf; C_Disc_D6.0mm_W2.5mm_P5.00mm
C17: 100uf; CP_Radial_D8.0mm_P3.80mm
C19: 2200uf; CP_Radial_D24.0mm_P10.00mm_SnapIn
C20, C26: 0.1uf; C_Disc_D6.0mm_W4.4mm_P5.00mm
C21, C24: 470uf; CP_Radial_D10.0mm_P3.80mm
C22: 10uf; CP_Radial_D8.0mm_P3.50mm
C23: 0.01uf; C_Disc_D6.0mm_W4.4mm_P5.00mm
C25: 100uf; CP_Radial_D8.0mm_P3.50mm
D1: 1N4007; D_DO-41_SOD81_P10.16mm_Horizontal
D2: LED; LED_D5.0mm
J1: RCJ-014; CUI_RCJ-014; PART_REV B
J2: Conn_02x20_Odd_Even; IDC-Header_2x20_P2.54mm_Vertical
J3: Barrel_Jack_MountingPin; BarrelJack_Horizontal
J4: Conn_01x04; JST_VH_B4P-VH-B_1x04_P3.96mm_Vertical
J5: JST PH 1x2; JST_PH_B2B-PH-K_1x02_P2.00mm_Vertical
JP1: Jumper_2_Open; PinHeader_1x02_P2.54mm_Vertical
JP2: Jumper_3_Open; PinHeader_1x03_P2.54mm_Vertical
Q1: 2N3904; TO-92_Inline
R1, R2: 300; R_Axial_DIN0309_L9.0mm_D3.2mm_P12.70mm_Horizontal
R3, R4, R5, R6, R9: 2.2k; R_Axial_DIN0309_L9.0mm_D3.2mm_P12.70mm_Horizontal
R7, R10: 3.3k; R_Axial_DIN0309_L9.0mm_D3.2mm_P12.70mm_Horizontal
R8: 75; R_Axial_DIN0309_L9.0mm_D3.2mm_P12.70mm_Horizontal
R11: 10; R_Axial_DIN0309_L9.0mm_D3.2mm_P12.70mm_Horizontal
R12: 330; R_Axial_DIN0309_L9.0mm_D3.2mm_P12.70mm_Horizontal
RV1: 10k; Potentiometer_ACP_CA9-V10_Vertical
RV2: 1k; Potentiometer_Bourns_3266Y_Vertical
S1: 300SP1J1BLKM6QE; SW_300SP1J1BLKM6QE; PARTREV F
U1: 74LS04; DIP-14_W7.62mm
U2, U10: 74LS76; DIP-16_W7.62mm
U3, U4, U11, U12: 74LS93; DIP-14_W7.62mm
U5, U9: 74LS74; DIP-14_W7.62mm
U6: 74LS00; DIP-14_W7.62mm
U7: 74LS30; DIP-14_W7.62mm
U8: 74LS10; DIP-14_W7.62mm
U13, U15: 74LS02; DIP-14_W7.62mm
U14: 74LS86; DIP-14_W7.62mm
U16: 74LS125; DIP-14_W7.62mm
U18: LM386; DIP-8_W7.62mm
U19: LM7805_TO220; TO-220-3_Vertical
Y1: 14.318Mhz; Crystal_HC18-U_Vertical

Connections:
1H: J2.38, U3.1 (CP1..3), U3.12 (Q0)
1V: J2.2, U8.13, U11.1 (CP1..3), U11.12 (Q0)
2H: J2.36, U3.9 (Q1), U7.12
2V: J2.4, U11.9 (Q1)
4H: J2.34, U3.8 (Q2), U7.11
4V: J2.6, U8.2, U8.5, U11.8 (Q2)
8H: J2.32, U3.11 (Q3), U4.14 (CP0)
8V: J2.8, U11.11 (Q3), U12.14 (CP0), U13.8, U13.9
16H: J2.30, U4.1 (CP1..3), U4.12 (Q0), U6.2
16V: J2.10, U12.1 (CP1..3), U12.12 (Q0), U13.6
32H: J2.28, U4.9 (Q1), U6.12
32V: J2.12, U12.9 (Q1)
64H: J2.26, U4.8 (Q2), U6.1, U7.6
64V: J2.14, U12.8 (Q2)
128H: J2.24, U2.6 (C), U4.11 (Q3), U7.5
128V: J2.16, U10.6 (C), U12.11 (Q3)
256H: J2.22, U2.11 (Q), U7.4
256V: J2.18, U8.1, U10.11 (Q)
+5V: C2.1, C3.1, C4.1, C5.1, C6.1, C7.1, C8.1, C9.1, C10.1, C11.1, C12.1, C13.1, C14.1, C15.1, C16.1, C17.1, C18.1, C25.1, C26.1, D2.2 (A), J4.1, J4.4, Q1.3 (C), R3.2, R4.2, R5.2, R6.2, R9.2, U1.14 (VCC), U2.2 (~S), U2.3 (~R), U2.4 (J), U2.5 (VCC), U2.16 (K), U3.5 (VCC), U4.5 (VCC), U5.14 (VCC), U6.14 (VCC), U7.14 (VCC), U8.14 (VCC), U9.10 (~S), U9.13 (~R), U9.14 (VCC), U10.5 (VCC), U10.7 (~S), U10.9 (J), U10.12 (K), U11.5 (VCC), U12.5 (VCC), U13.14 (VCC), U14.5, U14.14 (VCC), U15.14 (VCC), U16.14 (VCC), U19.3 (VO)
+9V: C19.1, C20.1, C21.1, D1.1 (K), J2.9, J2.11, U18.6 (V+), U19.1 (VI)
AUDIN: J2.15, RV1.1
CSYNC: J2.21, U14.6, U16.2
CVID: J2.25, JP1.1 (A), JP2.3 (B), RV2.3
GND: C2.2, C3.2, C4.2, C5.2, C6.2, C7.2, C8.2, C9.2, C10.2, C11.2, C12.2, C13.2, C14.2, C15.2, C16.2, C17.2, C18.2, C19.2, C20.2, C21.2, C25.2, C26.2, J1.1A (1), J1.1B (1), J1.1C (1), J3.2, J4.2, J4.3, J5.2, R7.1, R8.1, R10.1, R11.1, R12.1, RV1.3, U1.7 (GND), U2.13 (GND), U3.10 (GND), U4.10 (GND), U5.7 (GND), U6.7 (GND), U7.7 (GND), U8.7 (GND), U9.7 (GND), U10.13 (GND), U11.10 (GND), U12.10 (GND), U13.7 (GND), U14.7 (GND), U15.7 (GND), U16.7 (GND), U18.2 (-), U18.4 (GND), U19.2 (GND)
GVID: J2.29, U15.2, U15.3
HBLANK: J2.3, U6.5, U6.8, U6.13, U15.12
HCLK: J2.40, U2.15 (Q), U3.14 (CP0), U5.11 (C)
HRST: J2.5, U3.2 (R0(1)), U3.3 (R0(2)), U4.2 (R0(1)), U4.3 (R0(2)), U5.8 (~Q), U9.11 (C), U11.14 (CP0)
HSYNC: U6.11, U14.1
unnamed: C1.1, R2.1, U1.5
unnamed: C1.2, R1.2, U1.2, U1.3
unnamed: C22.1, U18.1 (GAIN)
unnamed: C22.2, U18.8 (GAIN)
unnamed: C23.1, C24.1, U18.5
unnamed: C23.2, R11.2
unnamed: C24.2, J5.1
unnamed: D1.2 (A), S1.3
unnamed: D2.1 (K), R12.2
unnamed: J3.1, S1.2
unnamed: JP2.1 (A), Q1.1 (E), R8.2
unnamed: JP1.2 (B), Q1.2 (B), R6.1, R7.2
unnamed: R1.1, U1.1, Y1.1
unnamed: R2.2, U1.6, Y1.2
unnamed: R3.1, U7.1, U7.2, U7.3
unnamed: R4.1, U2.7 (~S), U2.9 (J), U2.12 (K)
unnamed: R5.1, U5.10 (~S), U5.13 (~R)
unnamed: R9.1, R10.2, RV2.1, RV2.2, U16.3
unnamed: RV1.2, U18.3 (+)
unnamed: S1.S1 (SHIELD), S1.S2 (SHIELD)
unnamed: U1.4, U2.1 (C)
unnamed: U2.8 (~R), U5.9 (Q), U6.10
unnamed: U5.12 (D), U7.8
unnamed: U6.3, U6.4
unnamed: U6.6, U6.9
unnamed: U8.4, U13.10
unnamed: U8.12, U9.12 (D)
unnamed: U9.9 (Q), U10.8 (~R)
unnamed: U13.1, U13.5
unnamed: U13.11, U14.3, U14.4
unnamed: U13.12, U15.4
unnamed: U13.13, U16.1
unnamed: U8.6, U14.2
unnamed: U15.1, U15.5
unnamed: U15.6, U15.10
unnamed: U15.8, U15.9, U15.13
VBLANK: J2.37, U8.3, U13.3, U13.4, U15.11
VIDEOOUT: J1.2, JP2.2 (C)
VRST: J2.35, U9.8 (~Q), U11.2 (R0(1)), U11.3 (R0(2)), U12.2 (R0(1)), U12.3 (R0(2)), U13.2

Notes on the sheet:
Place jumper on JP1 and pins 1 and 2 of JP2 for amplified composite signal
TTL 1-bit Video Board
POWER
HORIZONTAL VIDEO
2x22 2.54 PIN HEADER FOR EXTERNAL CONNECTION
AUDIO
VERTICAL VIDEO

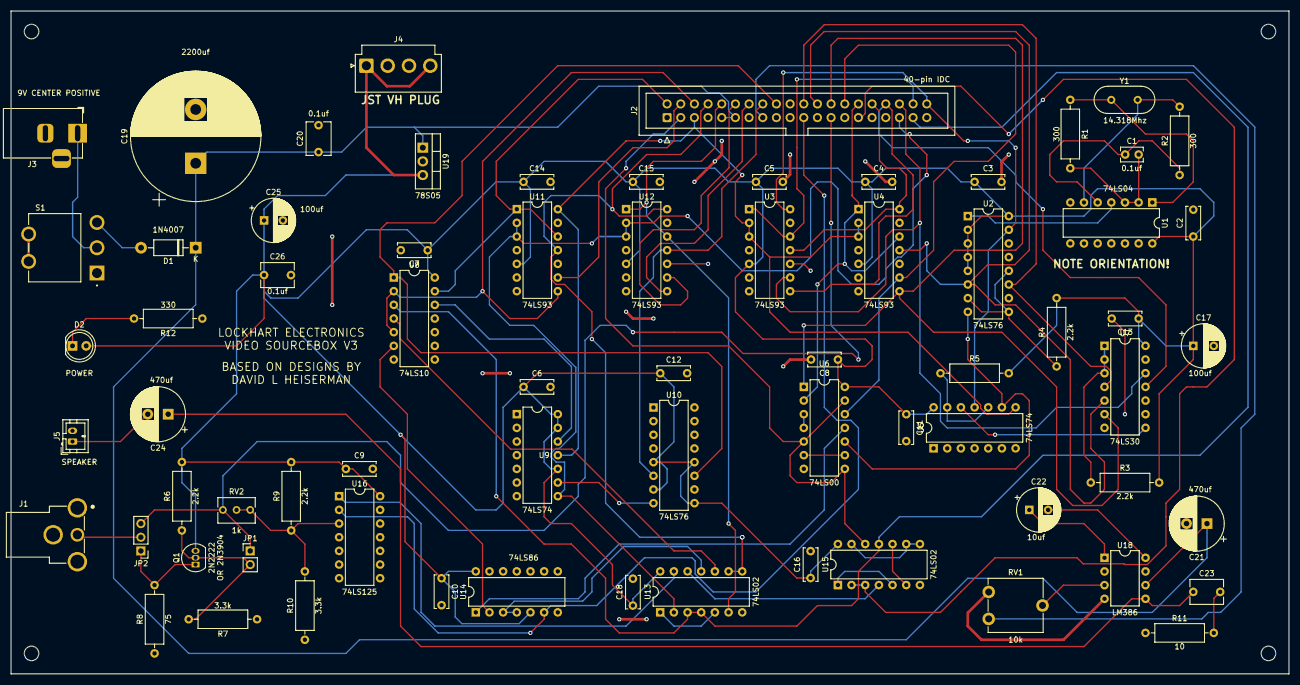
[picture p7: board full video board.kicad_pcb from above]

Board: 2 copper layers, 237.5 x 123.2 mm, 70 parts (0 on the bottom side), 68 nets.

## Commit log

2025-02-02 Update README.md
    Mentioning new board revision and changes contained therein.
2025-02-02 Update and rename full video board BOM.csv to OLD/full video board BOM.csv
    [full video board BOM.csv]
2025-02-02 Update and rename full video board.kicad_pcb to OLD/full video board.kicad_pcb
    [full video board.kicad_pcb]
2025-02-02 Update and rename full video board.kicad_sch to OLD/full video board.kicad_sch
    [full video board.kicad_sch]
2025-02-02 Rename full video board.pdf to OLD/full video board.pdf
2025-02-02 Update and rename videoboard_gerber/full video board-B_Cu.gbr to OLD/oldgerber/full video board-B_Cu.gbr
    [full video board-B_Cu.gbr]
2025-02-02 Update and rename videoboard_gerber/full video board-B_Mask.gbr to OLD/oldgerber/full video board-B_Mask.gbr
    [full video board-B_Mask.gbr]
2025-02-02 Update and rename videoboard_gerber/full video board-B_Paste.gbr to OLD/oldgerber/full video board-B_Paste.gbr
    [full video board-B_Paste.gbr]
2025-02-02 Update and rename videoboard_gerber/full video board-B_Silkscreen.gbr to OLD/oldgerber/full video board-B_Silkscreen.gbr
    [full video board-B_Silkscreen.gbr]
2025-02-02 Update and rename videoboard_gerber/full video board-Edge_Cuts.gbr to OLD/oldgerber/full video board-Edge_Cuts.gbr
    [full video board-Edge_Cuts.gbr]
2025-02-02 Update and rename videoboard_gerber/full video board-F_Cu.gbr to OLD/oldgerber/full video board-F_Cu.gbr
    [full video board-F_Cu.gbr]
2025-02-02 Update and rename videoboard_gerber/full video board-F_Mask.gbr to OLD/oldgerber/full video board-F_Mask.gbr
    [full video board-F_Mask.gbr]
2025-02-02 Update and rename videoboard_gerber/full video board-F_Paste.gbr to OLD/oldgerber/full video board-F_Paste.gbr
    [full video board-F_Paste.gbr]
2025-02-02 Update and rename videoboard_gerber/full video board-F_Silkscreen.gbr to OLD/oldgerber/full video board-F_Silkscreen.gbr
    [full video board-F_Silkscreen.gbr]
2025-02-02 Update and rename videoboard_gerber/full video board-NPTH-drl_map.gbr to OLD/oldgerber/full video board-NPTH-drl_map.gbr
    [full video board-NPTH-drl_map.gbr]
2025-02-02 Update and rename videoboard_gerber/full video board-NPTH.drl to OLD/oldgerber/full video board-NPTH.drl
    [full video board-NPTH.drl]
2025-02-02 Update and rename videoboard_gerber/full video board-PTH-drl_map.gbr to OLD/oldgerber/full video board-PTH-drl_map.gbr
    [full video board-PTH-drl_map.gbr]
2025-02-02 Update and rename videoboard_gerber/full video board-PTH.drl to OLD/oldgerber/full video board-PTH.drl
    [full video board-PTH.drl]
2025-02-02 Update and rename videoboard_gerber/full video board-job.gbrjob to OLD/oldgerber/full video board-job.gbrjob
    [full video board-job.gbrjob]
2025-02-02 new gerbers for new pcb revision
2025-02-02 Rename full video boardREV3.zip to gerbers/full video boardREV3.zip
2025-05-17 Delete gerbers directory
    old gerbers for previous revision with incorrect flip-flop IC; replacing with correct ones
    [full video boardREV2-B_Cu.gbr, full video boardREV2-B_Mask.gbr, full video boardREV2-B_Paste.gbr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]
2025-05-17 Add files via upload
    Updated KiCad project files.
    [full video boardREV2.csv, full video boardREV2.kicad_pcb, full video boardREV2.kicad_sch]
